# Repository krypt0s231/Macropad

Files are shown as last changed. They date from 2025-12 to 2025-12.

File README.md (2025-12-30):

# KRYPT's Hackpad – Custom 4×4 KMK Macropad with OLED & RGB

A custom-designed 4×4 mechanical macropad built around the Seeed XIAO RP2040, featuring:

Matrix-scanned mechanical switches with diodes

SK6812 Mini RGB LEDs

0.91" OLED display

KMK firmware (CircuitPython)

PC-side system monitoring (CPU / RAM / GPU / Disk)

This project was designed as a DIY / competition-grade hackpad, from schematic → PCB → firmware → case.

# Project Images

  ## **Schematic**
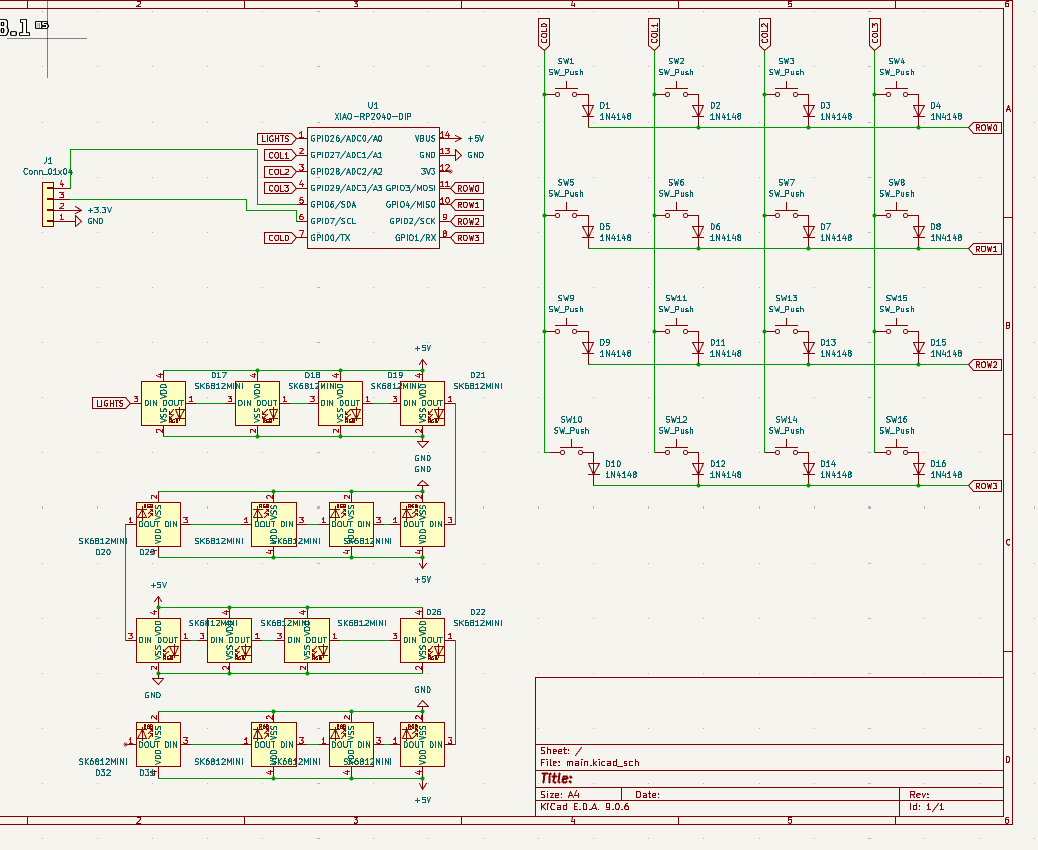
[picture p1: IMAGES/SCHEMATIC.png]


  ## **PCB Layout**
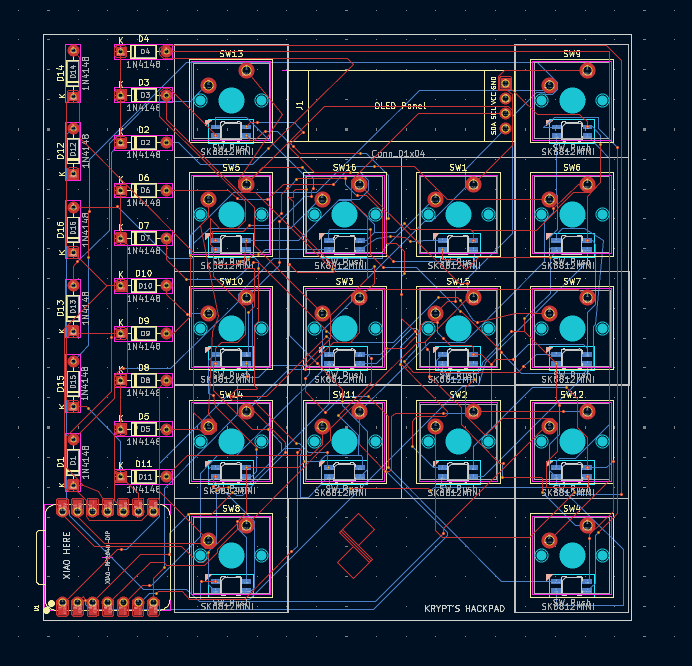
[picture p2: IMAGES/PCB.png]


  ## **Case & Assembly**
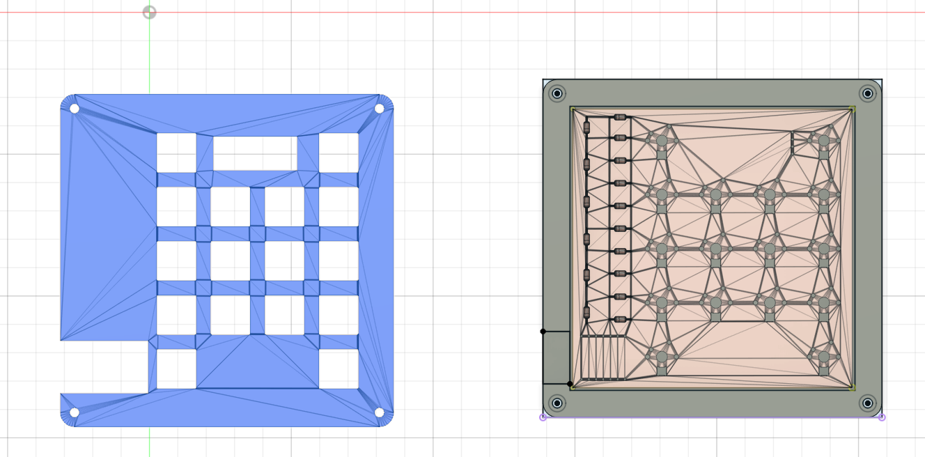
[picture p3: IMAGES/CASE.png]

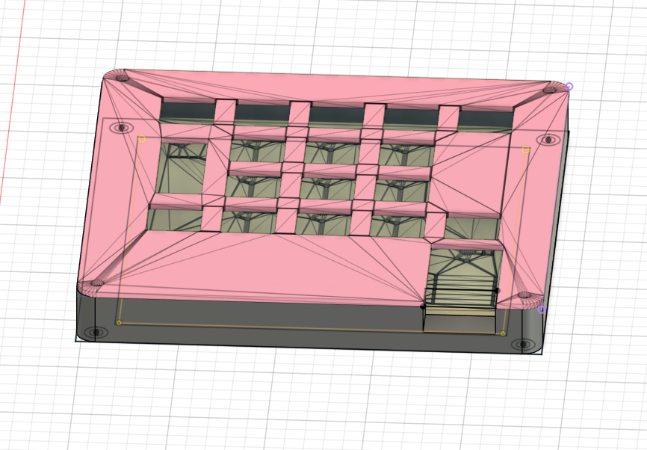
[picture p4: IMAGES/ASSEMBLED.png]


# Hardware Overview

MCU: Seeed Studio XIAO RP2040

Switches: MX-style mechanical switches

Matrix: 4 Rows × 4 Columns with 1N4148 diodes

RGB: SK6812 Mini (NeoPixel compatible)

Display: 0.91" OLED (SSD1306, 128×32)

Power: USB-C

# Pin Mapping
***Matrix***

**Columns**

COL0 → GPIO0

COL1 → GPIO27

COL2 → GPIO28

COL3 → GPIO29

**Rows**

ROW0 → GPIO3

ROW1 → GPIO4

ROW2 → GPIO2

ROW3 → GPIO1

**Peripherals**

RGB Data: GPIO26

OLED: I²C (default XIAO pins)

# Firmware

Keyboard firmware: KMK (CircuitPython)

Features:

Matrix scanning

RGB underglow

OLED display

USB HID data input from PC

#The OLED displays:

 CPU usage

 RAM usage

 GPU usage

 Disk (C:) usage

System statistics are sent from a PC-side Python script over USB HID.

# PC-side Software

A Python helper script runs on the host computer to:

Read system stats (via psutil, GPUtil)

Send data to the keyboard using HID

This architecture is similar to Stream Decks and professional macro pads.

# Author

Designed and built by kryptos

License

Open-sourse

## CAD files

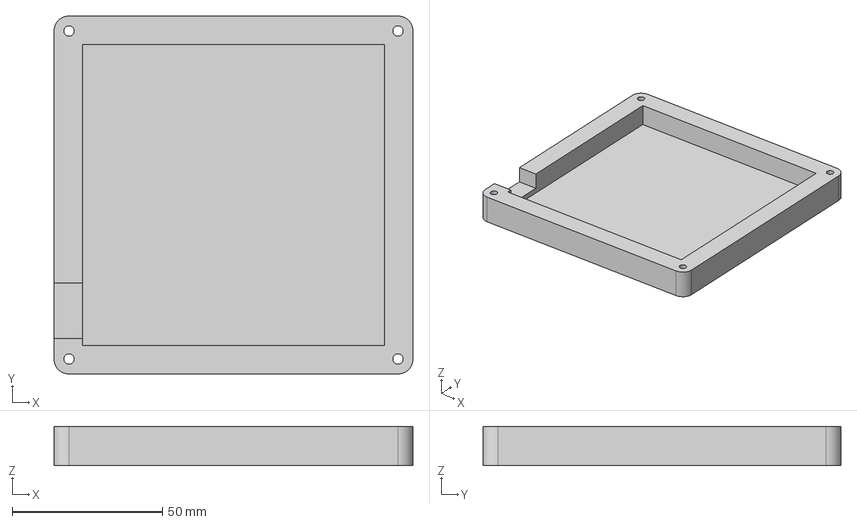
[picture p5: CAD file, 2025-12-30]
CAD/FINAL.step
119.5 x 119.2 x 13.0 mm

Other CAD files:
CAD/CAD.step

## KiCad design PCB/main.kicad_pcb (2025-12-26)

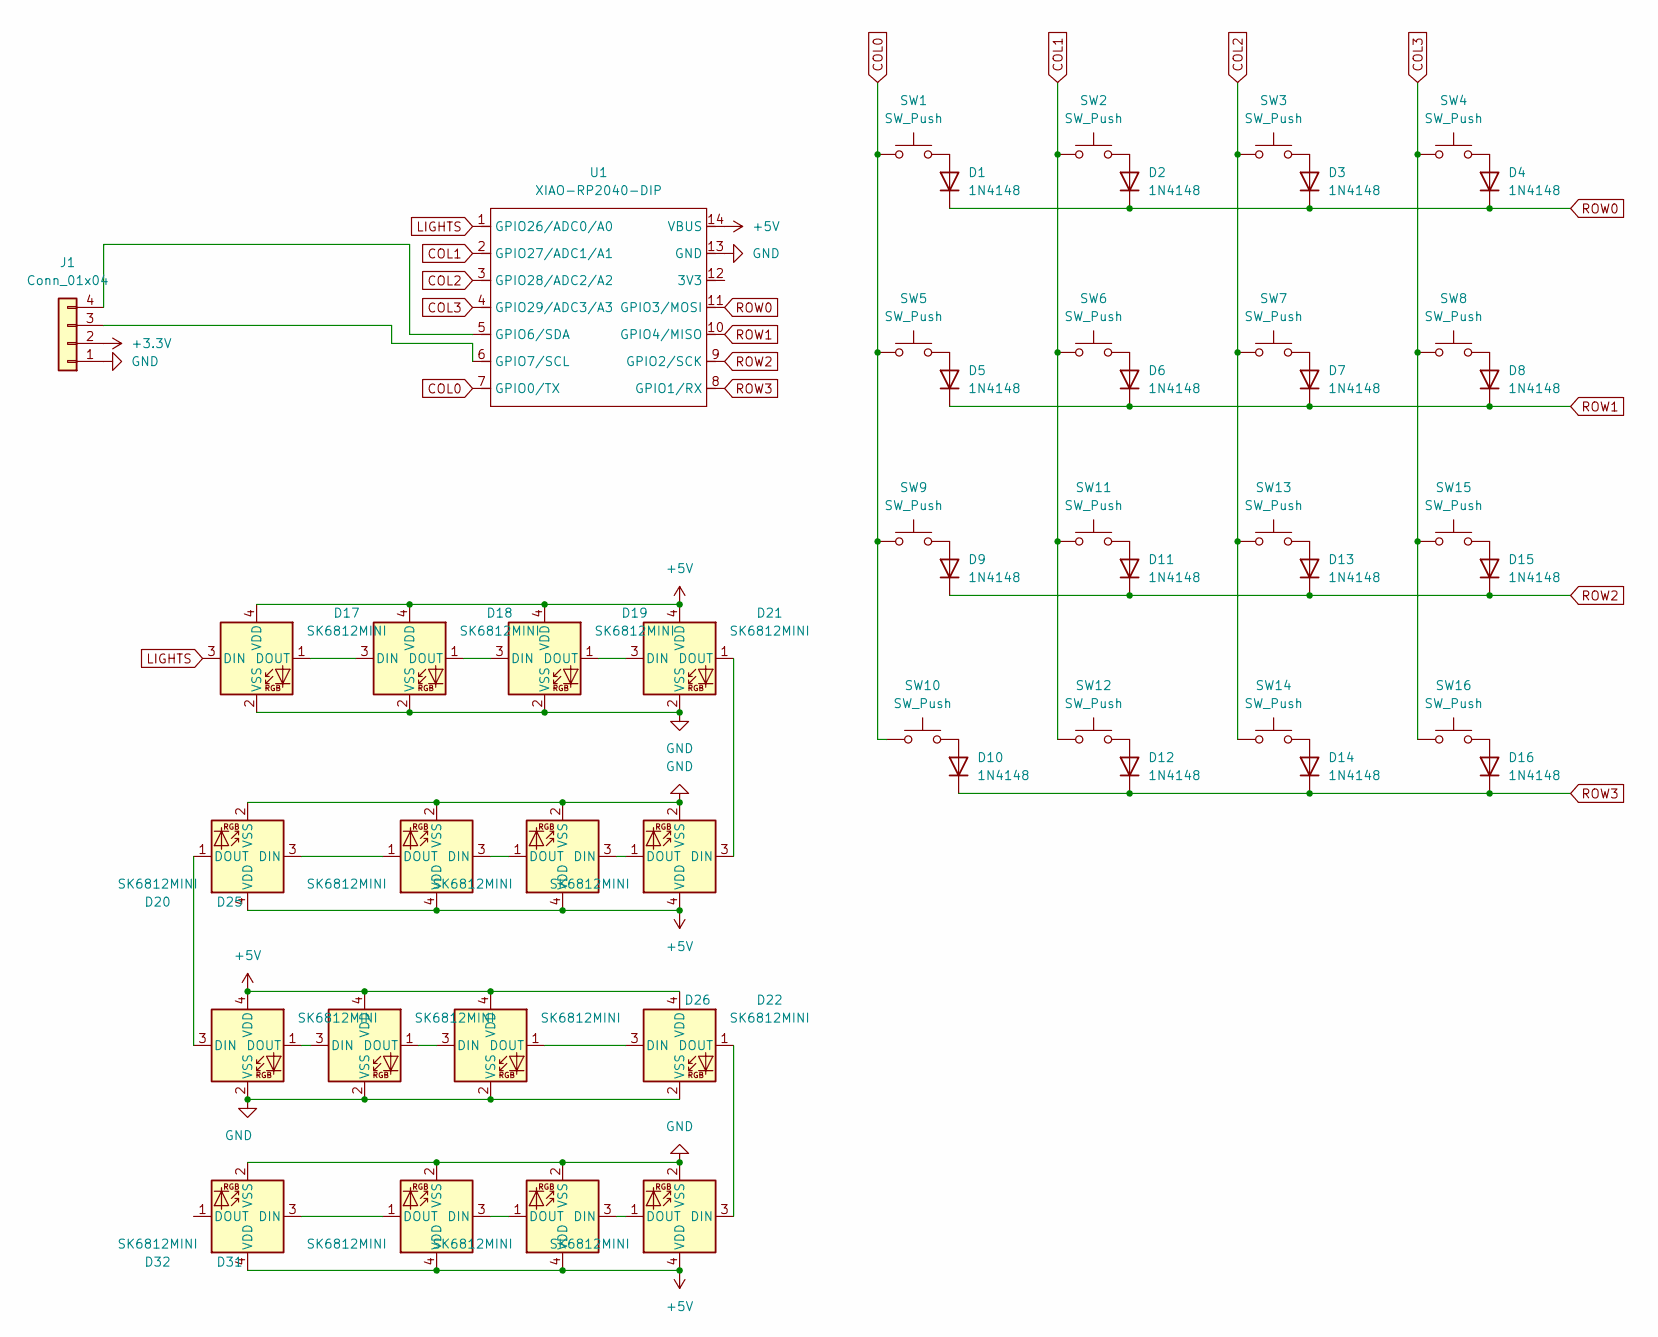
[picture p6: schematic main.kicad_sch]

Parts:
D1, D2, D3, D4, D5, D6, D7, D8, D9, D10, D11, D12, D13, D14, D15, D16: 1N4148; D_DO-35_SOD27_P7.62mm_Horizontal
D17, D18, D19, D20, D21, D22, D23, D24, D25, D26, D27, D28, D29, D30, D31, D32: SK6812MINI; MX_SK6812MINI-E_REV
J1: Conn_01x04; SSD1306-0.91-OLED-4pin-128x32
SW1, SW2, SW3, SW4, SW5, SW6, SW7, SW8, SW9, SW10, SW11, SW12, SW13, SW14, SW15, SW16: SW_Push; SW_Cherry_MX_1.00u_PCB
U1: XIAO-RP2040-DIP

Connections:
+3.3V: J1.2
+5V: D17.4 (VDD), D18.4 (VDD), D19.4 (VDD), D20.4 (VDD), D21.4 (VDD), D22.4 (VDD), D23.4 (VDD), D24.4 (VDD), D25.4 (VDD), D26.4 (VDD), D27.4 (VDD), D28.4 (VDD), D29.4 (VDD), D30.4 (VDD), D31.4 (VDD), D32.4 (VDD), U1.14 (VBUS)
COL0: SW1.1, SW5.1, SW9.1, SW10.1, U1.7 (GPIO0/TX)
COL1: SW2.1, SW6.1, SW11.1, SW12.1, U1.2 (GPIO27/ADC1/A1)
COL2: SW3.1, SW7.1, SW13.1, SW14.1, U1.3 (GPIO28/ADC2/A2)
COL3: SW4.1, SW8.1, SW15.1, SW16.1, U1.4 (GPIO29/ADC3/A3)
GND: D17.2 (VSS), D18.2 (VSS), D19.2 (VSS), D20.2 (VSS), D21.2 (VSS), D22.2 (VSS), D23.2 (VSS), D24.2 (VSS), D25.2 (VSS), D26.2 (VSS), D27.2 (VSS), D28.2 (VSS), D29.2 (VSS), D30.2 (VSS), D31.2 (VSS), D32.2 (VSS), J1.1, U1.13 (GND)
LIGHTS: D17.3 (DIN), U1.1 (GPIO26/ADC0/A0)
unnamed: D1.2 (A), SW1.2
unnamed: D2.2 (A), SW2.2
unnamed: D3.2 (A), SW3.2
unnamed: D4.2 (A), SW4.2
unnamed: D5.2 (A), SW5.2
unnamed: D6.2 (A), SW6.2
unnamed: D7.2 (A), SW7.2
unnamed: D8.2 (A), SW8.2
unnamed: D9.2 (A), SW9.2
unnamed: D10.2 (A), SW10.2
unnamed: D11.2 (A), SW11.2
unnamed: D12.2 (A), SW12.2
unnamed: D13.2 (A), SW13.2
unnamed: D14.2 (A), SW14.2
unnamed: D15.2 (A), SW15.2
unnamed: D16.2 (A), SW16.2
unnamed: D17.1 (DOUT), D18.3 (DIN)
unnamed: D18.1 (DOUT), D19.3 (DIN)
unnamed: D19.1 (DOUT), D21.3 (DIN)
unnamed: D20.3 (DIN), D25.1 (DOUT)
unnamed: D20.1 (DOUT), D28.3 (DIN)
unnamed: D21.1 (DOUT), D23.3 (DIN)
unnamed: D22.3 (DIN), D26.1 (DOUT)
unnamed: D22.1 (DOUT), D29.3 (DIN)
unnamed: D23.1 (DOUT), D24.3 (DIN)
unnamed: D24.1 (DOUT), D25.3 (DIN)
unnamed: D26.3 (DIN), D27.1 (DOUT)
unnamed: D27.3 (DIN), D28.1 (DOUT)
unnamed: D29.1 (DOUT), D30.3 (DIN)
unnamed: D30.1 (DOUT), D31.3 (DIN)
unnamed: D31.1 (DOUT), D32.3 (DIN)
unnamed: J1.3, U1.6 (GPIO7/SCL)
unnamed: J1.4, U1.5 (GPIO6/SDA)
ROW0: D1.1 (K), D2.1 (K), D3.1 (K), D4.1 (K), U1.11 (GPIO3/MOSI)
ROW1: D5.1 (K), D6.1 (K), D7.1 (K), D8.1 (K), U1.10 (GPIO4/MISO)
ROW2: D9.1 (K), D11.1 (K), D13.1 (K), D15.1 (K), U1.9 (GPIO2/SCK)
ROW3: D10.1 (K), D12.1 (K), D14.1 (K), D16.1 (K), U1.8 (GPIO1/RX)

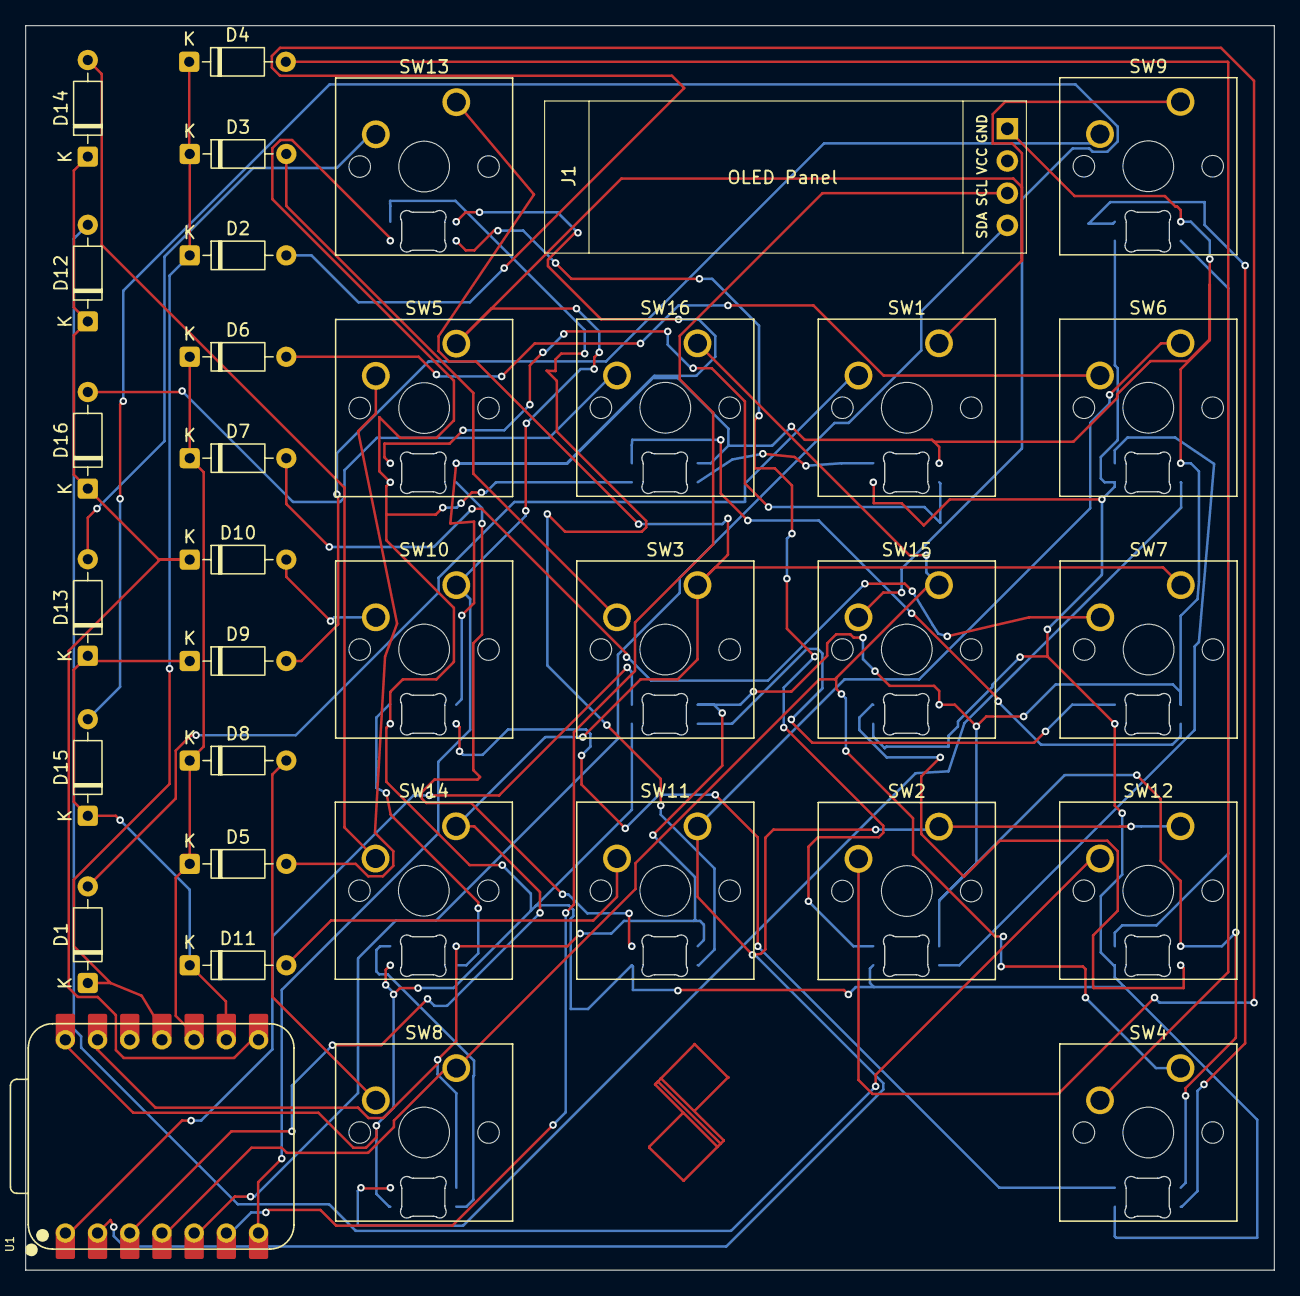
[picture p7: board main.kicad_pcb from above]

Board: 2 copper layers, 98.5 x 98.2 mm, 50 parts (0 on the bottom side), 44 nets.
